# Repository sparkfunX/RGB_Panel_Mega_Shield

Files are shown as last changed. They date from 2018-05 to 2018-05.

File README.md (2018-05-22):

SparkFun RGB Panel Mega Shield
========================================

SparkFun RGB Panel Mega Shield

[*SparkX RGB Panel Mega Shield (SPX-14753)*](https://www.sparkfun.com/products/14753)

RGB panels are excellent fun but wiring them up can be a pain. This simple shield for Arduino connects the necessary 14 digital pins to drive our [32x32 RGB panel](https://www.sparkfun.com/products/14646) and our larger [32x64 RGB panel](https://www.sparkfun.com/products/14718). This comes as a bag of parts but once you've soldered the handful of components it's as easy as plugging on the 2x8 connector from the RGB panel to the shield and you're off to the races.

This shield was designed to leverage the power and memory space of the Mega. It is guaranteed to work with our [32x32 RGB panel](https://www.sparkfun.com/products/14646) and our [32x64 RGB panel](https://www.sparkfun.com/products/14718) but has been designed to work with nearly all 32x32 and 32x64 pixel panels available on the market. 

**Note:** This shield routes the CLK signal to pin 11. This makes the shield compatible with both Uno and Mega but you will need to change the define at the top of your sketch to:

    #define CLK 11

SparkFun labored with love to create this product. Feel like supporting open source hardware? 
Buy a [board](https://www.sparkfun.com/products/14753) from SparkFun!

Repository Contents
-------------------

* **/Hardware** - Eagle design files (.brd, .sch)

License Information
-------------------

This product is _**open source**_! 

Please review the LICENSE.md file for license information. 

If you have any questions or concerns on licensing, please contact techsupport@sparkfun.com.

Please use, reuse, and modify these files as you see fit. Please maintain attribution to SparkFun Electronics and release any derivative under the same license.

Distributed as-is; no warranty is given.

- Your friends at SparkFun.

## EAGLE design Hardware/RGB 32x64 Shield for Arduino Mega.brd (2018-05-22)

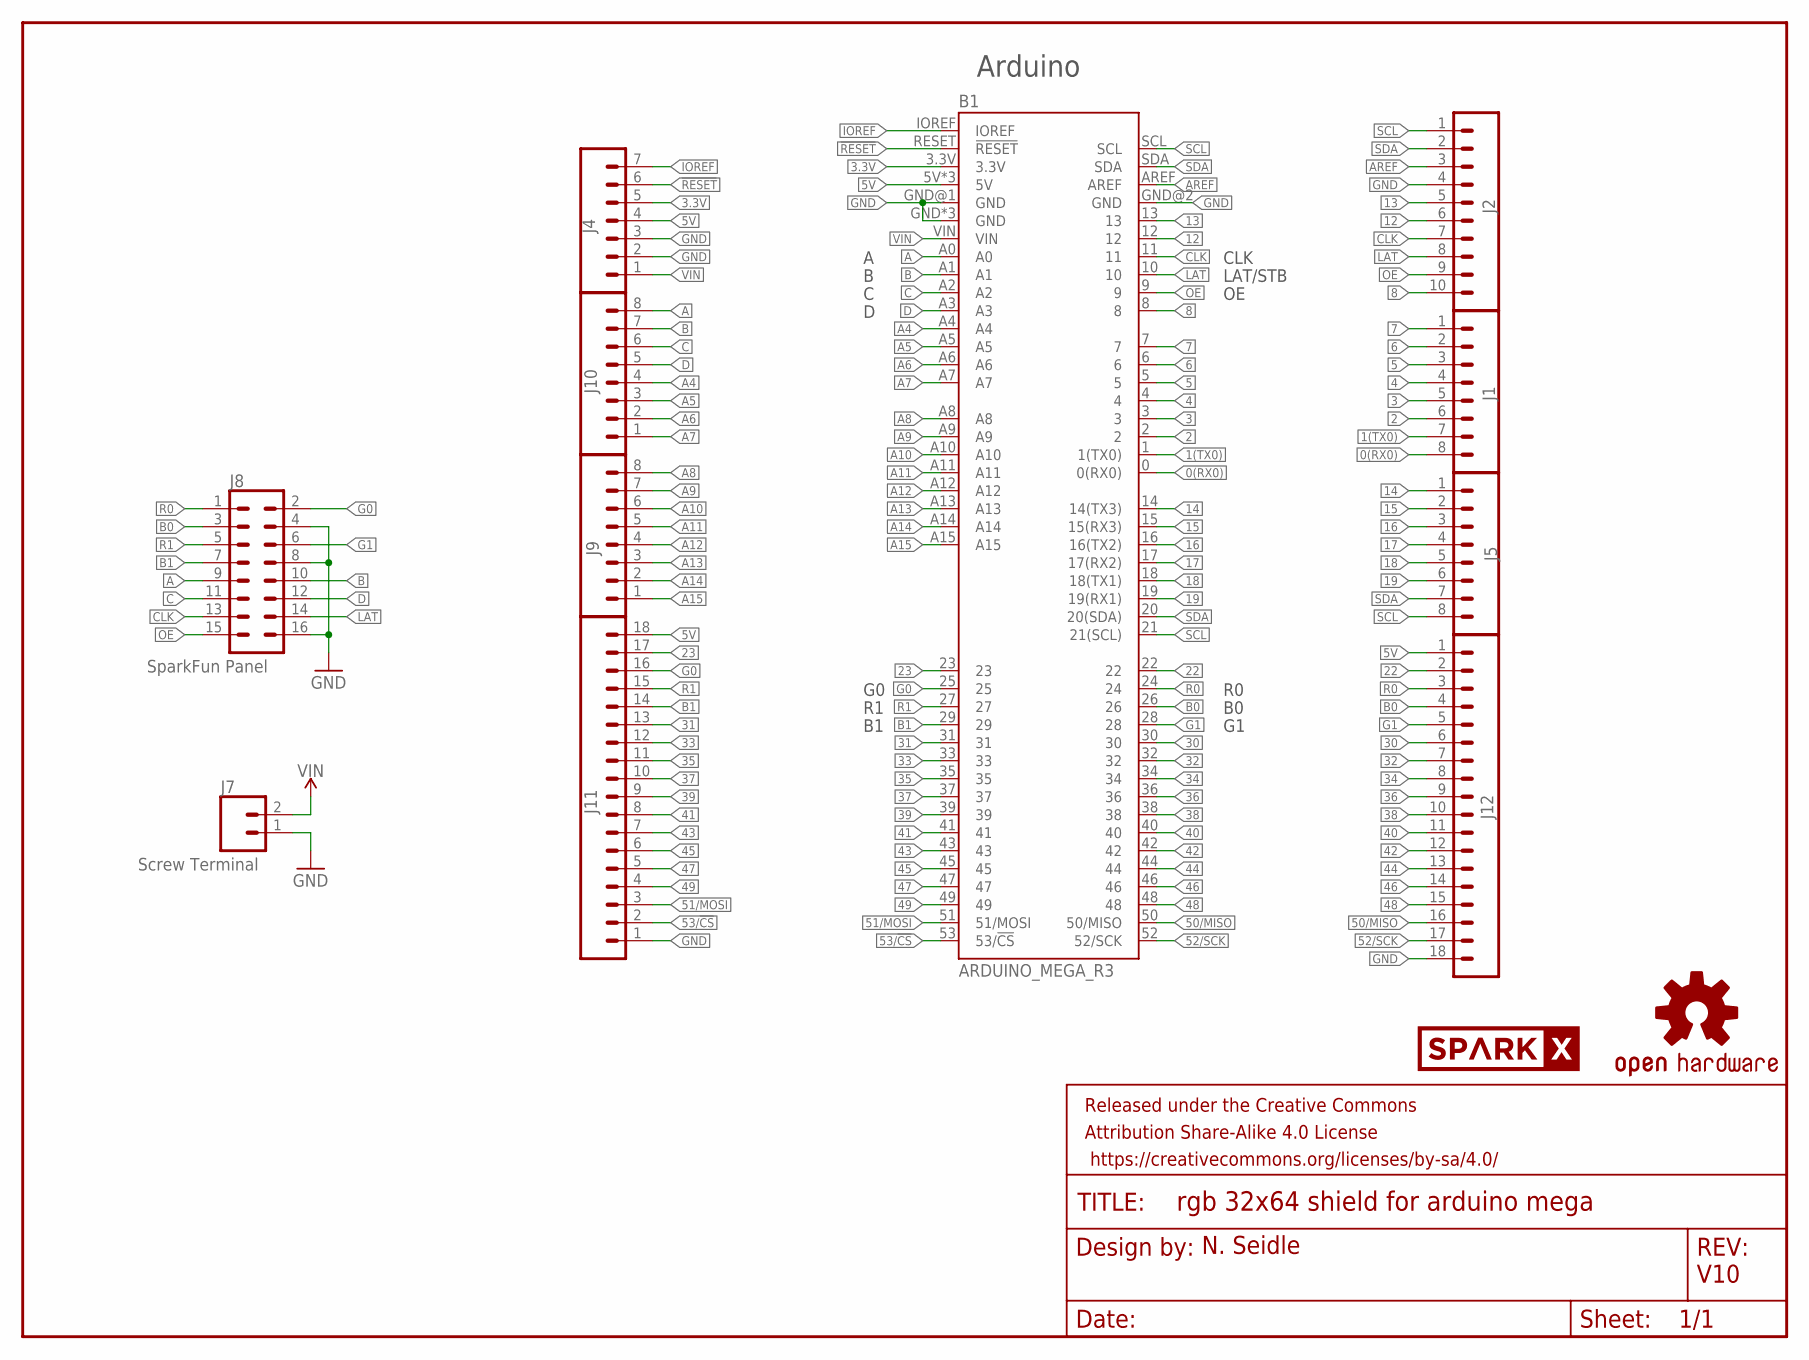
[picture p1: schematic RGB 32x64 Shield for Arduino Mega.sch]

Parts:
B1: ARDUINO_MEGA_R3; ARDUINO_MEGA_NO_SILK
FRAME1: FRAME-LETTER; CREATIVE_COMMONS
J1, J5, J9, J10: CONN_08NO_SILK_FEMALE_PTH; 1X08_NO_SILK
J2: CONN_10NO_SILK_PTH_FEMALE; 1X10_NO_SILK
J4: CONN_07NO_SILK; 1X07_NO_SILK
J7: Screw Terminal; SCREWTERMINAL-5MM-2
J8: SparkFun Panel; 2X8-SHROUDED_LOCK
J11, J12: CONN_18; 1X18_NO_SILK
LOGO1: OSHW-LOGOMINI; OSHW-LOGO-MINI
U$91: SPARKX-LOGO4; SPARKX-MEDIUM

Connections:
0(RX0): B1.0 (0(RX0)), J1.8
1(TX0): B1.1 (1(TX0)), J1.7
2: B1.2, J1.6
3: B1.3, J1.5
3.3V: B1.3.3V, J4.5
4: B1.4, J1.4
5: B1.5, J1.3
5V: B1.5V, B1.5V@1 (5V), B1.5V@2 (5V), J4.4, J11.18, J12.1
6: B1.6, J1.2
7: B1.7, J1.1
8: B1.8, J2.10
12: B1.12, J2.6
13: B1.13, J2.5
14: B1.14 (14(TX3)), J5.1
15: B1.15 (15(RX3)), J5.2
16: B1.16 (16(TX2)), J5.3
17: B1.17 (17(RX2)), J5.4
18: B1.18 (18(TX1)), J5.5
19: B1.19 (19(RX1)), J5.6
22: B1.22, J12.2
23: B1.23, J11.17
30: B1.30, J12.6
31: B1.31, J11.13
32: B1.32, J12.7
33: B1.33, J11.12
34: B1.34, J12.8
35: B1.35, J11.11
36: B1.36, J12.9
37: B1.37, J11.10
38: B1.38, J12.10
39: B1.39, J11.9
40: B1.40, J12.11
41: B1.41, J11.8
42: B1.42, J12.12
43: B1.43, J11.7
44: B1.44, J12.13
45: B1.45, J11.6
46: B1.46, J12.14
47: B1.47, J11.5
48: B1.48, J12.15
49: B1.49, J11.4
50/MISO: B1.50 (50/MISO), J12.16
51/MOSI: B1.51 (51/MOSI), J11.3
52/SCK: B1.52 (52/SCK), J12.17
53/!CS: B1.53 (53/!CS), J11.2
!RESET: B1.RESET (!RESET), J4.6
A: B1.A0, J8.9, J10.8
A4: B1.A4, J10.4
A5: B1.A5, J10.3
A6: B1.A6, J10.2
A7: B1.A7, J10.1
A8: B1.A8, J9.8
A9: B1.A9, J9.7
A10: B1.A10, J9.6
A11: B1.A11, J9.5
A12: B1.A12, J9.4
A13: B1.A13, J9.3
A14: B1.A14, J9.2
A15: B1.A15, J9.1
AREF: B1.AREF, J2.3
B: B1.A1, J8.10, J10.7
B0: B1.26, J8.3, J12.4
B1: B1.29, J8.7, J11.14
C: B1.A2, J8.11, J10.6
CLK: B1.11, J2.7, J8.13
D: B1.A3, J8.12, J10.5
G0: B1.25, J8.2, J11.16
G1: B1.28, J8.6, J12.5
GND: B1.GND, B1.GND@1 (GND), B1.GND@2 (GND), B1.GND@3 (GND), B1.GND@4 (GND), J2.4, J4.2, J4.3, J7.1, J8.4, J8.8, J8.16, J11.1, J12.18
IOREF: B1.IOREF, J4.7
LAT: B1.10, J2.8, J8.14
OE: B1.9, J2.9, J8.15
R0: B1.24, J8.1, J12.3
R1: B1.27, J8.5, J11.15
SCL: B1.21 (21(SCL)), B1.SCL, J2.1, J5.8
SDA: B1.20 (20(SDA)), B1.SDA, J2.2, J5.7
VIN: B1.VIN, J4.1, J7.2

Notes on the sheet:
N. Seidle
Arduino
V10
CLK
LAT/STB

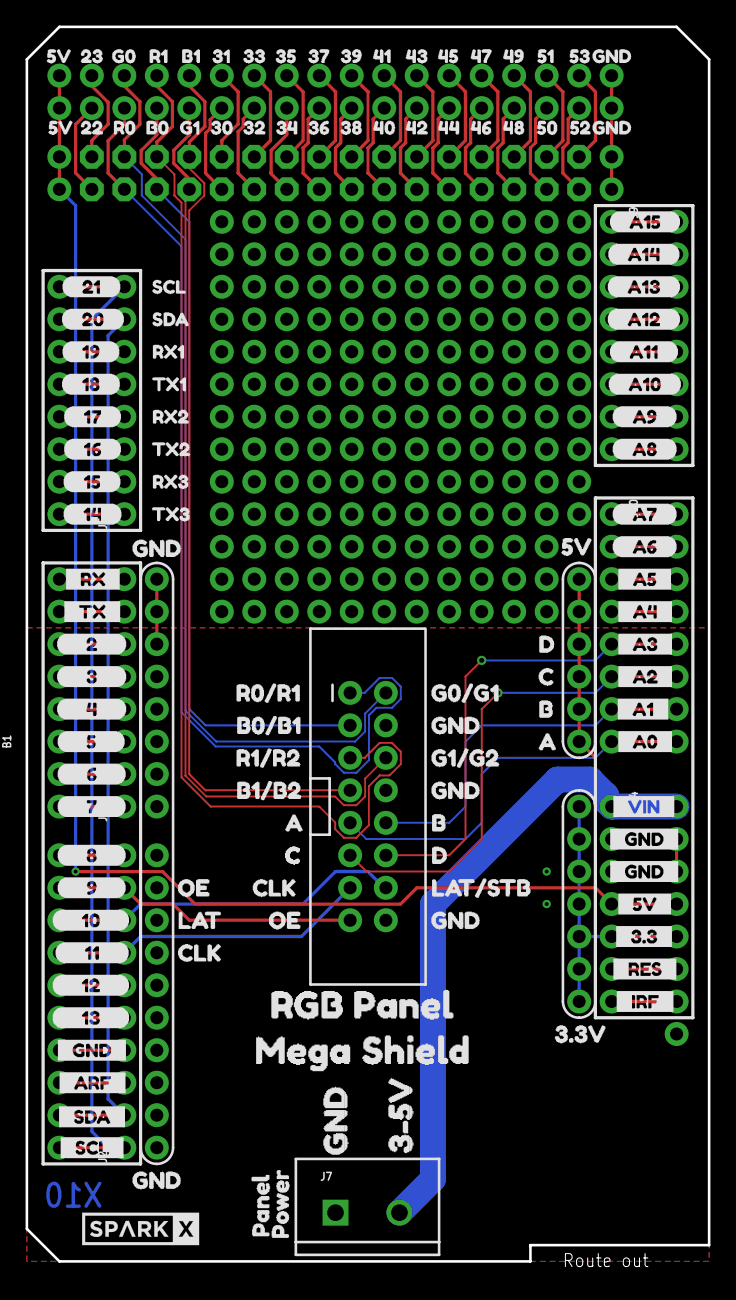
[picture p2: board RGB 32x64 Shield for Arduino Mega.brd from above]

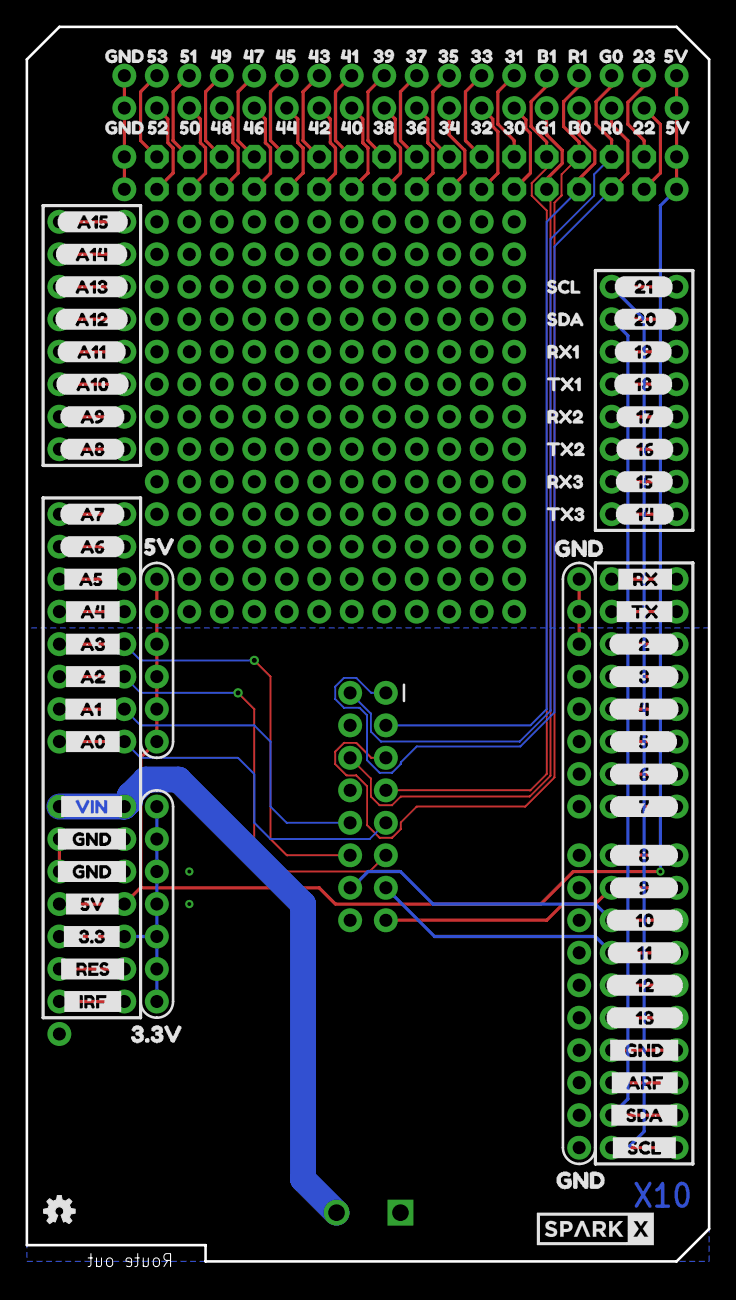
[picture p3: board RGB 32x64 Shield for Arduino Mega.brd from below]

Board: 2 copper layers, 53.3 x 96.5 mm, 240 parts (99 on the bottom side), 77 nets.

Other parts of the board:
U$1, U$34: D42
U$2, U$183: __A6__0
U$3, U$32, U$113: C37
U$4, U$38: GND48
U$5: 3#5V3
U$6, U$79: ____2____1
U$7, U$80: ____3____3
U$8, U$81: ____4____4
U$9, U$82: ____5____5
U$10, U$83: ____6____6
U$11: GND2
U$12, U$84: ____7____7
U$13, U$85: ____8____8
U$14, U$86: ____9____9
U$15, U$87: ____10____10
U$16: PANEL0
U$17, U$88: ____11____11
U$18, U$89: ____12____12
U$19: POWER1
U$20, U$90: ____13____13
U$21, U$22, U$37, U$108, U$109: GND40
U$23: RGB_PANEL2
U$24, U$73: __RX__0
U$25, U$110: 3#3V46
U$26, U$107: 5V47
U$27, U$45: __3#3__27
U$28, U$115: A36
U$29: B0#B132
U$30: B1#B235
U$31, U$114: B43
U$33, U$121: CLK38
U$35: G0#G145
U$36: G1#G244
U$39: LAT#STB41
U$40, U$122: OE39
U$41: R0#R131
U$42: R1#R234
U$43, U$48: __5V__26
U$44, U$62: __A0__23
U$46, U$63: __A1__22
U$47, U$64: __A2__21
U$49, U$65: __A3__20
U$50, U$66: __A4__19
U$51, U$72: __A5__18
U$52, U$74: __ARF__15
U$53, U$75: __GND__14
U$54, U$55, U$67, U$68: __GND__25
U$56, U$71: __IRF__29
U$57, U$69: __RES__28
U$58, U$76: __SCL__17
U$59, U$77: __SDA__16
U$60, U$78: __TX__0
U$61, U$70: __VIN__24
U$92, U$182: __A7__0
U$93, U$191: __A8__1
U$94, U$190: __A9__2
U$95, U$184: __A10__3
U$96, U$185: __A11__4
U$97, U$186: __A12__5
U$98, U$187: __A13__6
U$99, U$188: __A14__7
U$100, U$189: __A15__8
U$101, U$112: __14__0
U$102, U$116: __15__1
U$103, U$117: __16__2
U$104, U$118: __17__3
U$105, U$119: __18__4
U$106, U$120: __19__5
U$111, U$132: __20__6
U$123: LAT0
U$124: SHIELD0
U$125, U$134: __21__7
U$126, U$136: TX30
U$127, U$175: SDA2
U$128: SPARKX-MEDIUM
U$129, U$176: SCL3
U$130, U$177: RX31
U$131: MEGA4
U$133, U$223: 2232
U$135, U$137, U$205, U$224: GND0
U$138, U$178: RX14
U$139, U$179: RX22
U$140, U$180: TX13
U$141, U$181: TX21
U$142, U$143, U$192, U$210: 5V1
U$144, U$211: 469
U$145, U$193: 478
U$146, U$212: 487
U$147, U$194: 496
U$148, U$213: 505
U$149, U$195: 514
U$150, U$214: 523
U$151, U$196: 532
U$152, U$215: 3025
U$153, U$197: 3124
U$154, U$216: 3223
U$155, U$198: 3322
U$156, U$217: 3421
U$157, U$199: 3520
U$158, U$218: 3619
U$159, U$200: 3718
U$160, U$219: 3817
U$161, U$201: 3916
U$162, U$220: 4015
U$163, U$202: 4114
U$164, U$221: 4213
U$165, U$203: 4312
U$166, U$222: 4411
U$167, U$204: 4510
U$168, U$206: 230
U$169, U$225: B02
U$170, U$207: B14
U$171, U$208: G05
U$172, U$226: G16
U$173, U$227: R01
U$174, U$209: R13

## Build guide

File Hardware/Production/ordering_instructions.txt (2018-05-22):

panel size, 54x97mm
PCB thickness, 1.6mm
number of layers, 2
soldermask color, Black
silkscreen color, White
oz copper, 1oz
finish, HASL lead free
stencils, bottom
pcs per panel, 1

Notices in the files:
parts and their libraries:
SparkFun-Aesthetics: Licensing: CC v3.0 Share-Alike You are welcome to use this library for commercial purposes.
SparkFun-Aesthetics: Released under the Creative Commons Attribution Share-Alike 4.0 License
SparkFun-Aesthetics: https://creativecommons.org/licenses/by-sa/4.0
